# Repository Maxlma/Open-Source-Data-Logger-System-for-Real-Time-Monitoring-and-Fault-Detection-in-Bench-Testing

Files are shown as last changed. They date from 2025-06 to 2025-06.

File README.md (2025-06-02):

# 🧠 Smart Power Supply for Data Loggers

**Low-Cost / High-Precision UPS for Reliable Data Acquisition Systems**  
[Published in *Energies*, MDPI - DOI: [10.3390/en16010278](https://doi.org/10.3390/en16010278)]

## 📌 About the Project

This project presents the design and implementation of a **smart, low-cost, and high-precision power supply** system tailored for **data loggers** in experimental setups. It provides **uninterruptible power**, advanced **monitoring features**, and a **DIY-friendly open hardware** approach with robust performance under demanding conditions.

Developed by researchers from the **University of São Paulo (USP)** and the **University of Minho**, this power supply ensures uninterrupted operation even during AC power failures, thanks to an embedded UPS and smart control logic.

## ⚙️ Features

- 🔋 **AC/DC Dual Input** with seamless switching (UPS functionality)
- 📶 **Serial communication (UART)** with external devices
- 📺 **OLED Display** for real-time system status
- 🌡️ **Temperature monitoring** and **smart active cooling**
- 🔄 **Remote firmware update capability**
- 📏 Outputs: ±12V, 5V, 3.3V – bipolar and unipolar DC
- 🛡️ Protection: 3 internal fuses for AC input, DC section, and battery
- 🧠 Controlled by an **ATmega328PB** microcontroller
- 🧩 Fully documented open hardware – easily 3D printable case
- 💸 **Total cost under $150**

## 🧪 Experimental Results

Tests confirmed:

- **Switching time < 10 ms** between power sources  
- No voltage drop affecting operation under 0A, 1A, and 2A loads  
- Stable operation under AC loss scenarios  
- Precise voltage regulation and thermal control

## 📜 License

This project is licensed under the **Creative Commons BY 4.0**  
© 2022 by the authors. Reuse permitted with attribution.  
[License Details](https://creativecommons.org/licenses/by/4.0/)

## 👨‍🔬 Authors

- Márcio L. M. Amorim  
- Gabriel A. Ginja  
- João P. Carmo  
- Melkzedekue M. A. Moreira  
- Adriano A. G. Siqueira  
- José A. Afonso

## 📚 Citation

If you use this work, please cite:

> Amorim, M.L.M.; Ginja, G.A.; Carmo, J.P.; Moreira, M.M.A.; Siqueira, A.A.G.; Afonso, J.A.  
> *Low-Cost/High-Precision Smart Power Supply for Data Loggers.*  
> Energies 2023, 16, 278. DOI: [10.3390/en16010278](https://doi.org/10.3390/en16010278)

---

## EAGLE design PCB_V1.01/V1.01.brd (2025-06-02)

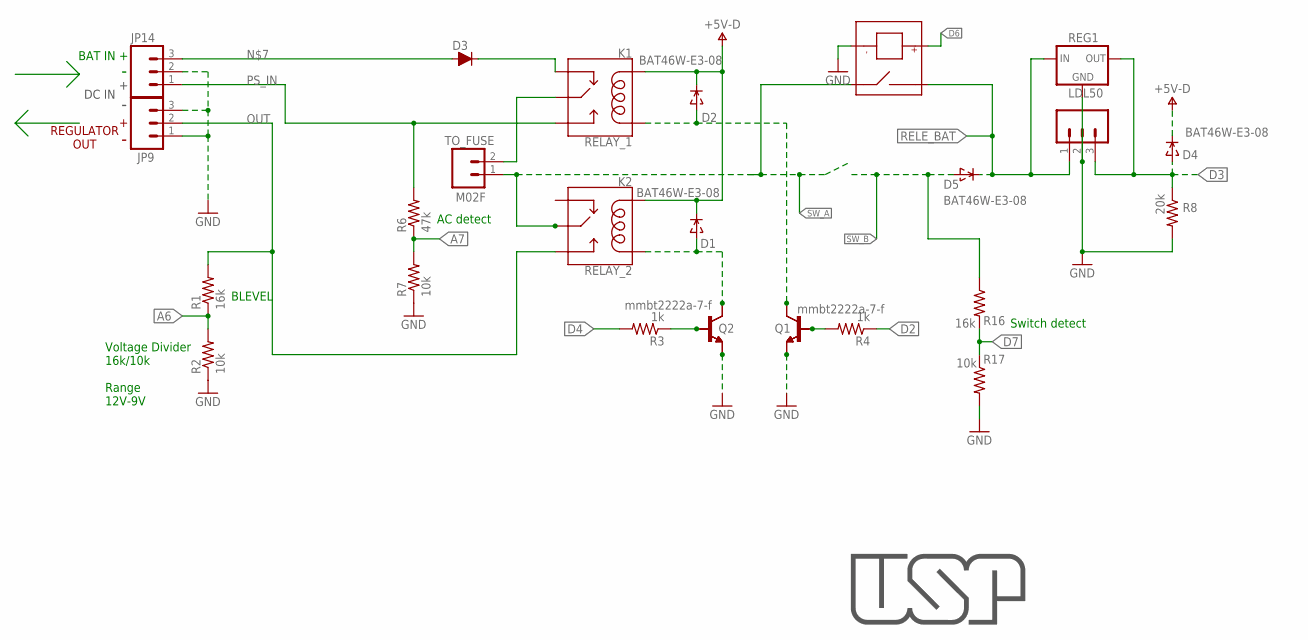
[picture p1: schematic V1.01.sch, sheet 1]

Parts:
7805: M03LOCK; 1X03_LOCK
D1, D2, D4, D5: BAT46W-E3-08; SOD-123
D3: DIODEFR; DIODE1.5A
JP9, JP14: M03; AK500
K1: RELAY_1; RELAY_G5LE
K2: RELAY_2; RELAY_G5LE
Q1, Q2: mmbt2222a-7-f; SOT23-3
Q3, Q4: TRANSISTOR-NPN-BC337; BC337
R1, R16: 16k; 0402
R2, R7, R17: 10k; 0402
R3, R4: 1k; 0402
R6: 47k; 0402
R8: 20k; 0402
REG1: LDL50; SOT223
RL1: RELAY_HE3621A0500; HE3621A
TO_FUSE: M02F; AK500M2

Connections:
+5V-D: D1.C, D2.C, D4.C, K1.2 (COIL1), K2.2 (COIL1); also elsewhere on the board
A6: R1.P$1 (1), R2.P$2 (2); also elsewhere on the board
A7: R6.P$1 (1), R7.P$2 (2); also elsewhere on the board
D2: R4.P$1 (1); also elsewhere on the board
D3: 7805.3, D4.A, R8.P$1 (1), REG1.2 (OUT), REG1.4 (OUT); also elsewhere on the board
D4: R3.P$2 (2); also elsewhere on the board
D6: RL1.P2; also elsewhere on the board
D7: R16.P$2 (2), R17.P$1 (1); also elsewhere on the board
GND: 7805.2, JP9.1, JP9.3, JP14.2, Q1.2 (E), Q2.2 (E), Q3.1 (E), Q4.1 (E), R2.P$1 (1), R7.P$1 (1), R8.P$2 (2), R17.P$2 (2), REG1.1 (GND), RL1.P3; also elsewhere on the board
unnamed: K1.1 (MAIN), TO_FUSE.2
unnamed: D2.A, K1.5 (COIL2), Q1.3 (C), Q4.3 (C)
unnamed: D1.A, K2.5 (COIL2), Q2.3 (C), Q3.3 (C)
unnamed: D3.A, JP14.3
unnamed: Q1.1 (B), Q4.2 (B), R4.P$2 (2)
unnamed: D3.C, K1.4 (NC)
OUT: JP9.2, K2.3 (NO), R1.P$2 (2)
PS_IN: JP14.1, K1.3 (NO), R6.P$2 (2)
RELE_BAT: 7805.1, D5.C, REG1.3 (IN), RL1.P1; also elsewhere on the board
STARTUP: Q2.1 (B), Q3.2 (B), R3.P$1 (1)
SW_A: K2.1 (MAIN), RL1.P4, TO_FUSE.1; also elsewhere on the board
SW_B: D5.A, R16.P$1 (1); also elsewhere on the board

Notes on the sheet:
BLEVEL
AC detect
Switch detect
BAT IN
REGULATOR OUT
DC IN
Voltage Divider 16k/10k Range 12V-9V

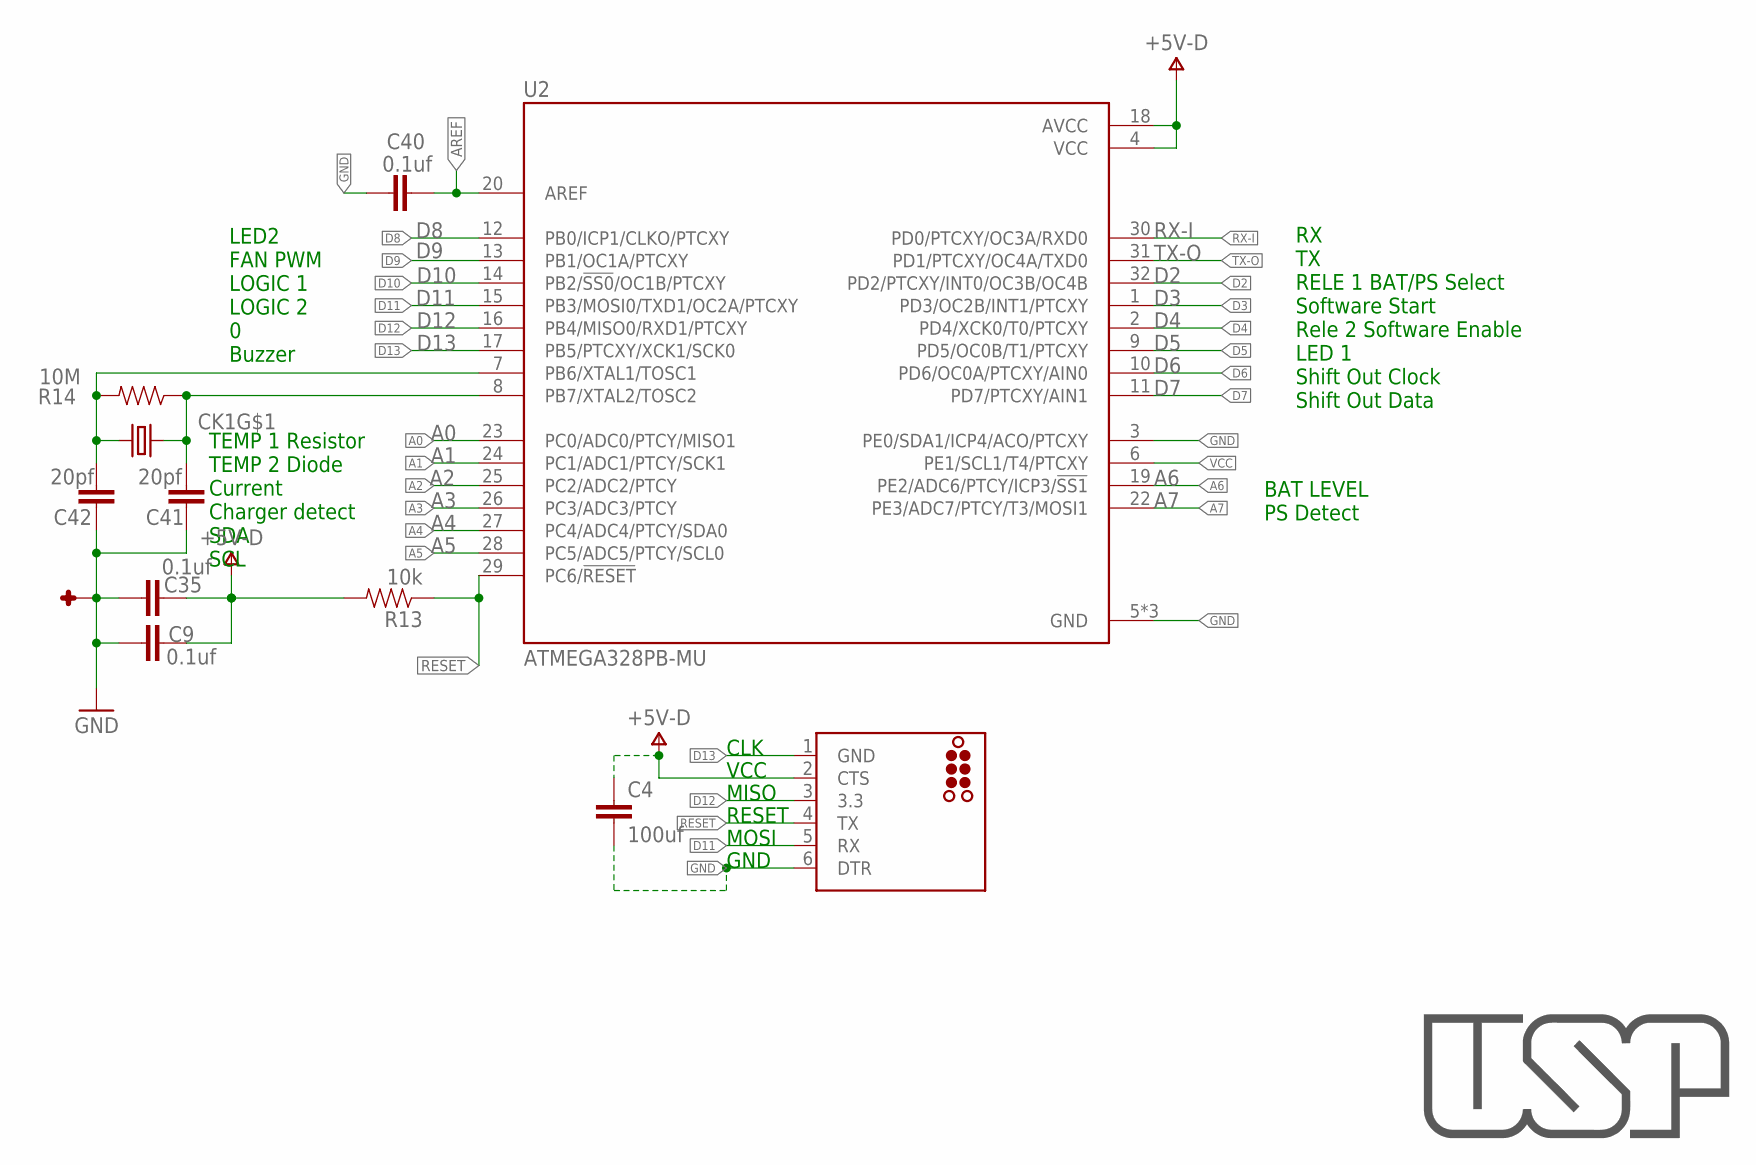
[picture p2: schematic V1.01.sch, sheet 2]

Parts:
C4: 100uf; 1206
C9, C35, C40: 0.1uf; 0402
C41, C42: 20pf; 0402
CK1: FA-238 16.0000MB-C3; 4-SMD@1
J10: DNP; TC2030-MCP-NL
R13: 10k; 0402
R14: 10M; 0402
U2: ATMEGA328PB-MU; QFN50P500X500X90-33N

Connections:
+5V-D: C4.1, C9.P$2 (2), C35.P$2 (2), J10.2 (CTS), R13.P$2 (2), U2.4 (VCC), U2.18 (AVCC); also elsewhere on the board
A0: U2.23 (PC0/ADC0/PTCY/MISO1); also elsewhere on the board
A1: U2.24 (PC1/ADC1/PTCY/SCK1); also elsewhere on the board
A2: U2.25 (PC2/ADC2/PTCY); also elsewhere on the board
A3: U2.26 (PC3/ADC3/PTCY); also elsewhere on the board
A4: U2.27 (PC4/ADC4/PTCY/SDA0); also elsewhere on the board
A5: U2.28 (PC5/ADC5/PTCY/SCL0); also elsewhere on the board
A6: U2.19 (PE2/ADC6/PTCY/ICP3/!SS1!); also elsewhere on the board
A7: U2.22 (PE3/ADC7/PTCY/T3/MOSI1); also elsewhere on the board
AREF: C40.P$1 (1), U2.20 (AREF)
D2: U2.32 (PD2/PTCXY/INT0/OC3B/OC4B); also elsewhere on the board
D3: U2.1 (PD3/OC2B/INT1/PTCXY); also elsewhere on the board
D4: U2.2 (PD4/XCK0/T0/PTCXY); also elsewhere on the board
D5: U2.9 (PD5/OC0B/T1/PTCXY)
D6: U2.10 (PD6/OC0A/PTCXY/AIN0); also elsewhere on the board
D7: U2.11 (PD7/PTCXY/AIN1); also elsewhere on the board
D8: U2.12 (PB0/ICP1/CLKO/PTCXY)
D9: U2.13 (PB1/OC1A/PTCXY); also elsewhere on the board
D10: U2.14 (PB2/!SS0!/OC1B/PTCXY)
D11: J10.5 (RX), U2.15 (PB3/MOSI0/TXD1/OC2A/PTCXY); also elsewhere on the board
D12: J10.3 (3.3), U2.16 (PB4/MISO0/RXD1/PTCXY)
D13: J10.1 (GND), U2.17 (PB5/PTCXY/XCK1/SCK0); also elsewhere on the board
GND: C4.2, C9.P$1 (1), C35.P$1 (1), C40.P$2 (2), C41.P$2 (2), C42.P$2 (2), CK1.GND1 (1), CK1.GND2 (1), J10.6 (DTR), U2.3 (PE0/SDA1/ICP4/ACO/PTCXY), U2.5 (GND), U2.21 (GND), U2.33 (GND); also elsewhere on the board
unnamed: C41.P$1 (1), CK1.P1 (1), R14.P$1 (1), U2.8 (PB7/XTAL2/TOSC2)
unnamed: C42.P$1 (1), CK1.P3 (2), R14.P$2 (2), U2.7 (PB6/XTAL1/TOSC1)
RESET: J10.4 (TX), R13.P$1 (1), U2.29 (PC6/!RESET!); also elsewhere on the board
RX-I: U2.30 (PD0/PTCXY/OC3A/RXD0); also elsewhere on the board
TX-O: U2.31 (PD1/PTCXY/OC4A/TXD0); also elsewhere on the board
VCC: U2.6 (PE1/SCL1/T4/PTCXY)

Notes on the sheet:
D11
RX TX RELE 1 BAT/PS Select Software Start Rele 2 Software Enable LED 1 Shift Out Clock Shift Out Data
LED2 FAN PWM LOGIC 1 LOGIC 2 0 Buzzer
TEMP 1 Resistor TEMP 2 Diode Current Charger detect SDA SCL
BAT LEVEL PS Detect
CLK VCC MISO RESET MOSI GND

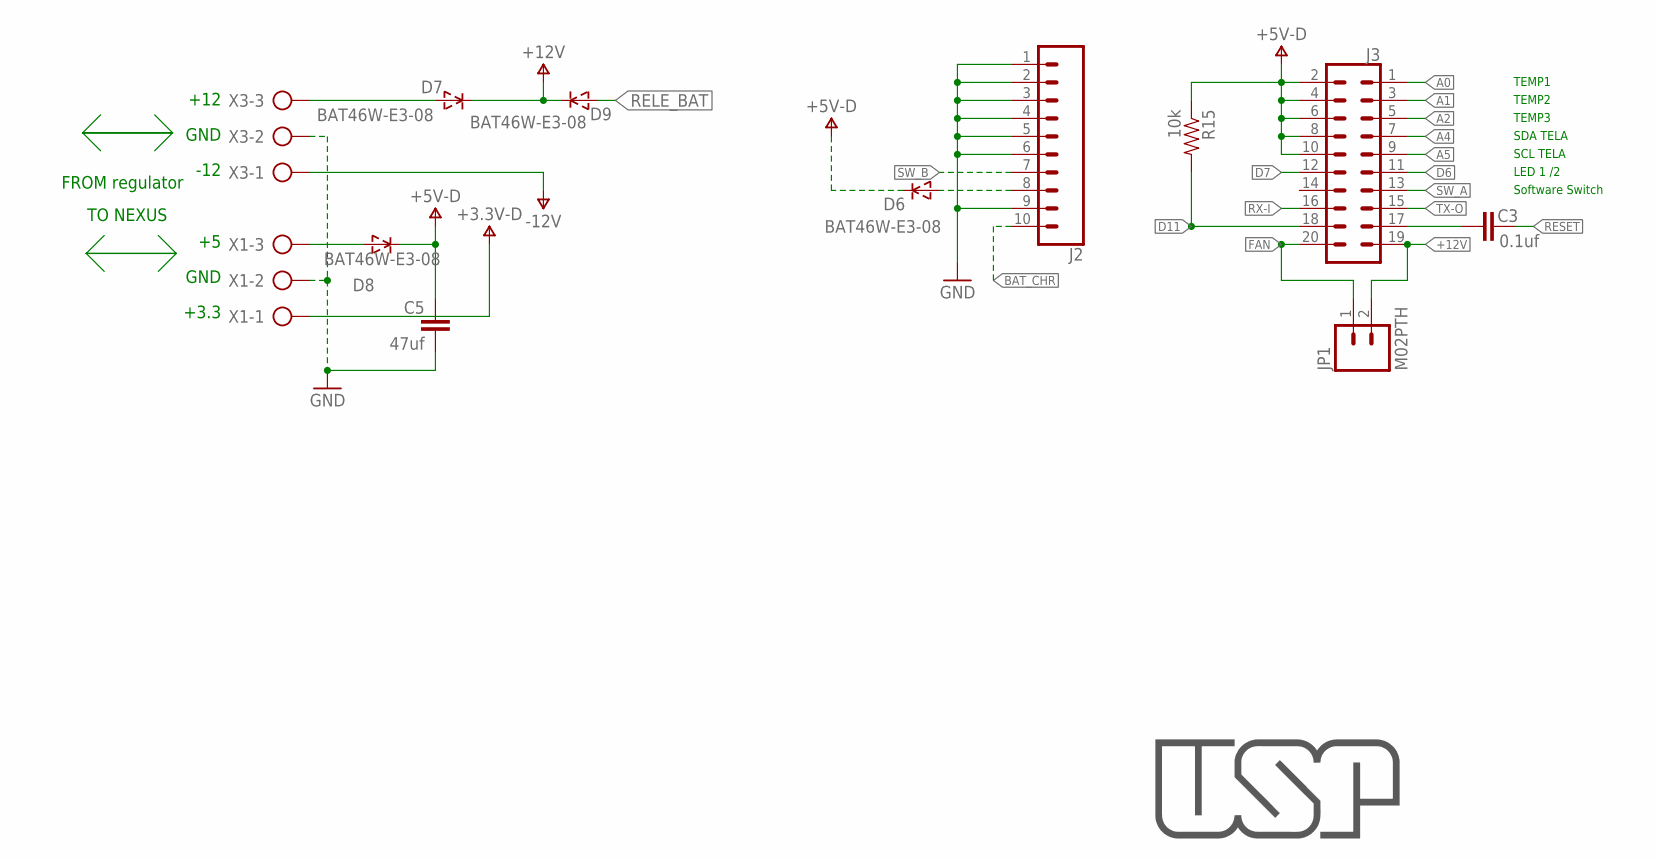
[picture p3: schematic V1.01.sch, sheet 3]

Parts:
C3: 0.1uf; 0402
C5: 47uf; 1206
D6, D7, D8, D9: BAT46W-E3-08; SOD-123
J2: CONN_10"; 1X10
J3: CONN_10X2; 2X10
JP1: M02PTH; 1X02
R15: 10k; 0402
X1, X3: AK500/3-H

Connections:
+3.3V-D: X1.1
+5V-D: C5.1, D6.C, D8.C, J3.2, J3.4, J3.6, J3.8, J3.10, R15.P$1 (1); also elsewhere on the board
+12V: D7.C, D9.C, J3.19, JP1.2
-12V: X3.1
A0: J3.1; also elsewhere on the board
A1: J3.3; also elsewhere on the board
A2: J3.5; also elsewhere on the board
A4: J3.7; also elsewhere on the board
A5: J3.9; also elsewhere on the board
BAT_CHR: J2.10; also elsewhere on the board
D6: J3.11; also elsewhere on the board
D7: J3.12; also elsewhere on the board
D11: J3.18, R15.P$2 (2); also elsewhere on the board
FAN: J3.20, JP1.1; also elsewhere on the board
GND: C5.2, J2.1, J2.2, J2.3, J2.4, J2.5, J2.6, J2.9, X1.2, X3.2; also elsewhere on the board
unnamed: D8.A, X1.3
unnamed: D6.A, J2.8
unnamed: D7.A, X3.3
RELE_BAT: D9.A; also elsewhere on the board
RESET: C3.P$2 (2); also elsewhere on the board
RESETT: C3.P$1 (1), J3.17
RX-I: J3.16; also elsewhere on the board
SW_A: J3.13; also elsewhere on the board
SW_B: J2.7; also elsewhere on the board
TX-O: J3.15; also elsewhere on the board

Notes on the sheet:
FROM regulator
+12 GND -12
TO NEXUS
TEMP1 TEMP2 TEMP3 SDA TELA SCL TELA LED 1 /2 Software Switch
+5 GND +3.3

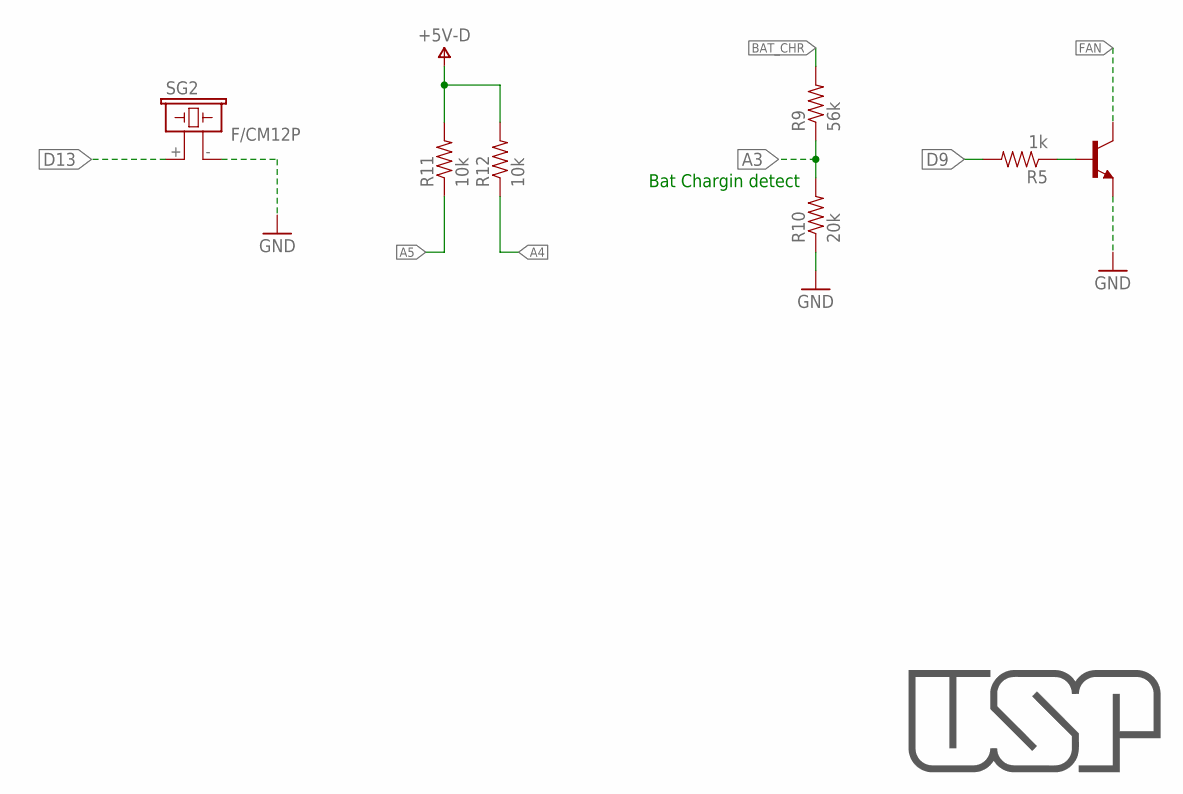
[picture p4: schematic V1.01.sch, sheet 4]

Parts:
Q5: TRANSISTOR-NPN-BC337; BC337
R5: 1k; 0402
R9: 56k; 0402
R10: 20k; 0402
R11, R12: 10k; 0402
SG2: F/CM12P

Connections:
+5V-D: R11.P$2 (2), R12.P$2 (2); also elsewhere on the board
A3: R9.P$1 (1), R10.P$2 (2); also elsewhere on the board
A4: R12.P$1 (1); also elsewhere on the board
A5: R11.P$1 (1); also elsewhere on the board
BAT_CHR: R9.P$2 (2); also elsewhere on the board
D9: R5.P$2 (2); also elsewhere on the board
D13: SG2.+ (1); also elsewhere on the board
FAN: Q5.3 (C); also elsewhere on the board
GND: Q5.1 (E), R10.P$1 (1), SG2.- (2); also elsewhere on the board
unnamed: Q5.2 (B), R5.P$1 (1)

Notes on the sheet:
Bat Chargin detect

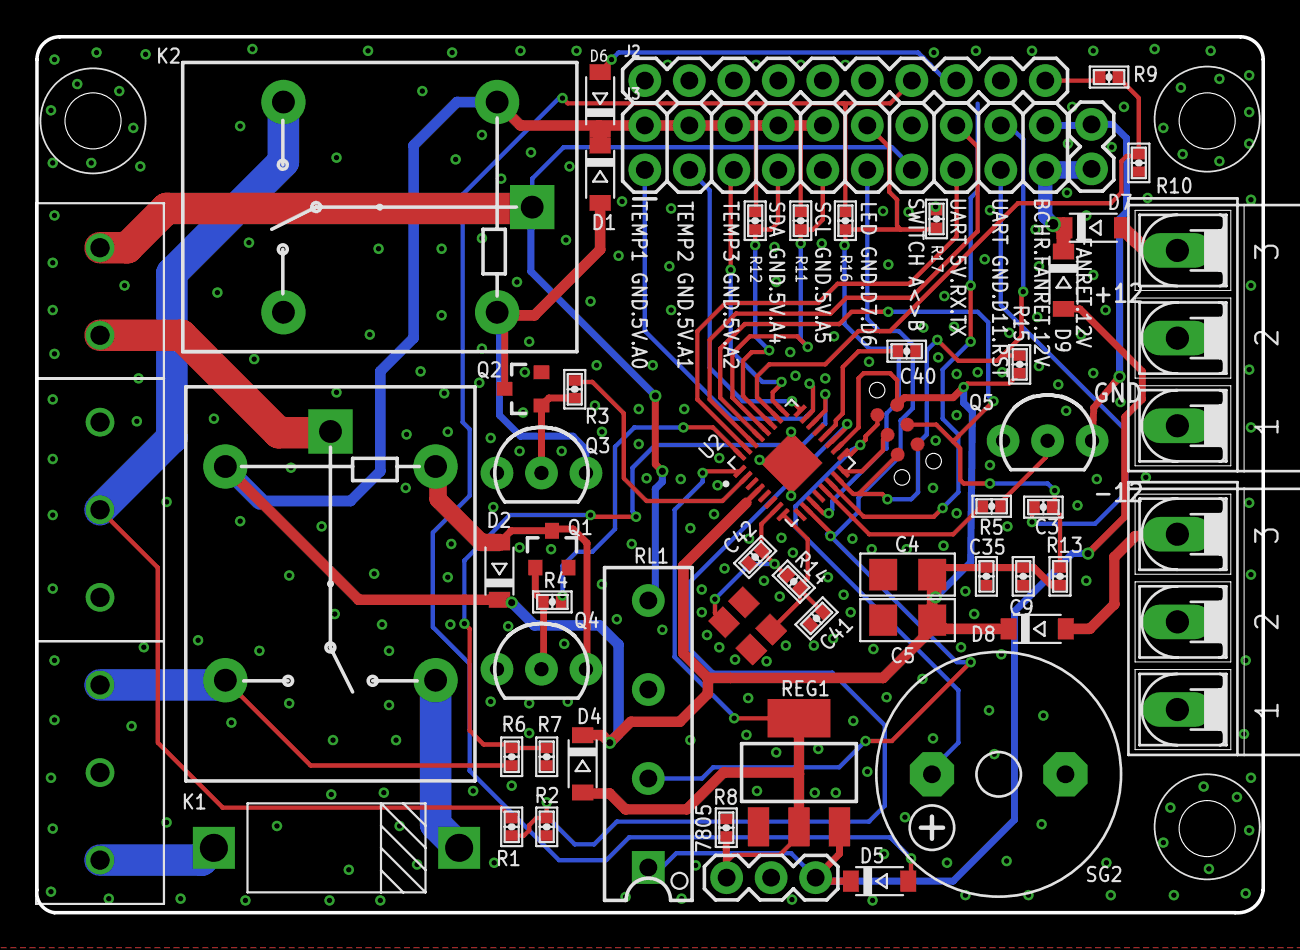
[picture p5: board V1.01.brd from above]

Board: 2 copper layers, 70.0 x 50.0 mm, 57 parts (1 on the bottom side), 45 nets.

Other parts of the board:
U$5: NEXUS2

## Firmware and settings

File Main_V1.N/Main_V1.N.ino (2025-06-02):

// PLACA FONTE Power Guard //
// Versão 1 HW V1.K             //
// Marcio Amorim Agosto 2022  //

//Portasd Analogicas:
//A0 Temperatura Resistor Carga
//A1 Temperatura Diodo Saida
//A2 Medidor de Corrente
//A3 Detector de Carga no modulo da bateria
//A4 SDA
//A5 SCL
//A6 NIVEL BATERIA
//A7 Detecta rede AC


// Lista de errors:
// Nao continua carga apos desligar e bateria carregando

#include <Wire.h>
#include <Adafruit_GFX.h>
#define SSD1306_128_32
#include <Adafruit_SSD1306.h>

Adafruit_SSD1306 display = Adafruit_SSD1306();

#define RELE1 4 //Rele que seleciona antrada bateria ou Carregador
#define RELE2 2 //Rele que seleciona SftwareStart do curcuito
#define ChargeRELE3 7 // Rele de modo sleep para carga AC
#define FAN 9
#define Wake 6
uint8_t Temp1 = 0;
uint8_t Temp2 = 0;
uint8_t Lowbat = 1;


bool ACstate = 0;
bool ButtonState = 0;
bool Wakeup = 0;
bool RemoteShutdown = 0;

uint8_t FANusage = 0;
uint8_t ButtonCount = 0;
uint8_t RScount = 0;


//AVG BAT LEVEL
uint8_t readings[12];
uint8_t readIndex1 = 0;
int total1 = 0;
uint8_t BatDisplay = 0;

// AVG TEMP LEVEL
uint8_t readings2[12];
uint8_t readIndex2 = 0;
uint16_t total2;
uint8_t TempAVG;

// AVG AMP LEVEL
int readings3[12];
uint8_t readIndex3 =0;
int total3 = 0;
uint16_t Ampere = 0; // medidor Ampere


void setup() {
  ///////////////DEFINICAO DE PINOS ////////////////////////////////////////////////////////////////////
  ///////////////DEFINICAO DE PINOS ////////////////////////////////////////////////////////////////////
  ///////////////DEFINICAO DE PINOS ////////////////////////////////////////////////////////////////////
  pinMode(RELE1, OUTPUT);
  pinMode(RELE2, OUTPUT);
  pinMode(ChargeRELE3, OUTPUT);
  pinMode(FAN, OUTPUT);
  pinMode(13, OUTPUT);
  pinMode(11, INPUT);
  pinMode(Wake, INPUT);
  Serial.begin(115200);
  Wire.begin();
  Startup();

  for (int thisReading = 0; thisReading < 12; thisReading++) {
    readings[thisReading] = 0;
  }
  for (int thisReading2 = 0; thisReading2 < 12; thisReading2++) {
    readings2[thisReading2] = 0;
  }
  for (int thisReading3 = 0; thisReading3 < 12; thisReading3++) {
    readings3[thisReading3] = 0;
  }
}
void(* resetFunc) (void) = 0;

void loop() {
  Shutdown();
  Display();
  Sensors();
  PiCom();
}

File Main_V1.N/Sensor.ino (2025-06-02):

///////////////////////////////////Funcoes de Sensores ////////////////////////////////////////////////////////////////////
///////////////////////////////////Funcoes de Sensores ////////////////////////////////////////////////////////////////////
///////////////////////////////////Funcoes de Sensores ////////////////////////////////////////////////////////////////////
void Sensors() {
  /////DETECTA REDE AC
  if (analogRead(A7) >= 800) {
    digitalWrite(RELE2, HIGH);
    ACstate = 1;
  }
  else {
    digitalWrite(RELE2, LOW);
    ACstate = 0;
  }
  //////Battery//////
  //  Voltage Divider 16k/10k
  //  Range 12V-9V
  //  12V = 4.615V = 812 ADC CARREGADA ou maior
  //  10V = 3.85V = 787 ADC Alerta bateria baixa
  //  9.5V - 3.65V = 752 ADC Alerta desligamento
  //  9V = 3.45V 705 ADC DESLIGAMENTO IMEDIATO(Nao passar de 9V)

  //BatDisplay = analogRead(A6);
  BatDisplay = map(analogRead(A6), 600, 970, 0, 100);
  total1 = total1 - readings[readIndex1];
  readings[readIndex1] = BatDisplay;
  total1 = total1 + readings[readIndex1];
  readIndex1 = readIndex1 + 1;
  if (readIndex1 >= 12) {
    readIndex1 = 0;
  }
  BatDisplay = total1 / 12;

  if (BatDisplay >= 100) {
    BatDisplay = 100;
  }

  if (BatDisplay <= 20) {
    if (Lowbat == 0) {
      digitalWrite(13, HIGH);
    }
    Lowbat++;
    if (Lowbat == 15) {
      digitalWrite(13, LOW);
    }
    if (Lowbat == 100) {
      Lowbat = 0;
    }
  }

  if (BatDisplay <= 5) {
    for (int x = 0; x <= 20; x++) {
      display.clearDisplay();
      display.setCursor(10, 0);
      display.print(">>>> WARNING <<<<");
      display.setCursor(16, 10);
      display.print("LOW BATTERY");
      display.setCursor(20, 20);
      display.print("FORCED SHUTDOWN");
      digitalWrite(13, HIGH);
      display.display();
      delay(150);
      display.clearDisplay();
      digitalWrite(13, LOW);
      display.display();
      delay(150);
    }
    digitalWrite(RELE1, LOW);
    resetFunc();
  }

  ////////Determina a maior temperatura, Resistor(Carregador) ou Diodo(USO)
  Temp1 = ((analogRead(A0) * 5.0) - 500) / 10;
  Temp2 = ((analogRead(A1) * 5.0) - 500) / 10;
  if (Temp1 >= Temp2) {
    total2 = total2 - readings2[readIndex2];
    readings2[readIndex2] = Temp1;
    total2 = total2 + readings2[readIndex2];
    readIndex2 = readIndex2 + 1;
    if (readIndex2 >= 12) {
      readIndex2 = 0;
    }
    TempAVG = total2 / 12;
  }
  if (Temp1 <= Temp2) {
    total2 = total2 - readings2[readIndex2];
    readings2[readIndex2] = Temp2;
    total2 = total2 + readings2[readIndex2];
    readIndex2 = readIndex2 + 1;
    if (readIndex2 >= 12) {
      readIndex2 = 0;
    }
    TempAVG = total2 / 12;
  }

  ////FAN VELOCIDADE
  if(TempAVG <=40){
    FANusage = 0;
    analogWrite(FAN, 0);
  }
  if((TempAVG >=45)&& (FANusage == 0)){
    FANusage = 1;
    analogWrite(FAN, 60);
  }
  if((TempAVG >=55)&& (FANusage == 1)){
    FANusage = 2;
    analogWrite(FAN, 160);
  }
  if((TempAVG>=65)&&(FANusage == 2)){
    FANusage = 3;
    analogWrite(FAN, 254);
  }

  if (TempAVG >= 90) {
    for (int x = 0; x <= 20; x++) {
      display.clearDisplay();
      display.setCursor(10, 0);
      display.print(">>>> WARNING <<<<");
      display.setCursor(16, 10);
      display.print("HIGH TEMPERATURE");
      display.setCursor(20, 20);
      display.print("FORCED SHUTDOWN");
      digitalWrite(13, HIGH);
      display.display();
      delay(150);
      display.clearDisplay();
      digitalWrite(13, LOW);
      display.display();
      delay(150);
    }
    digitalWrite(RELE1, LOW);
    resetFunc();
  }

  //CORRENTE
  //Caululo corrente
  //transformar ADC em tensao:
  //((5*ADC)/1023)= Tensao
  //tensao inicial 2.5V
  //Tensao final 3.4V
  //Corrente incremento relacao 0.01V para cada 100mA

  Ampere = map(analogRead(A2), 510, 700, 0, 5000);
  total3 = total3 - readings3[readIndex3];
  readings3[readIndex3] = Ampere;
  total3 = total3 + readings3[readIndex3];
  readIndex3 = readIndex3 + 1;
  if (readIndex3 >= 12) {
    readIndex3 = 0;
  }
  Ampere = total3 / 12;
  if (Ampere <= 0) {
    Ampere = 0;
  }
}

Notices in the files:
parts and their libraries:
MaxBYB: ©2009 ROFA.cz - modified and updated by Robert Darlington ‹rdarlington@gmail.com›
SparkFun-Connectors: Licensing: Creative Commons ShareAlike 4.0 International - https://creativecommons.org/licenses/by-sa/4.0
